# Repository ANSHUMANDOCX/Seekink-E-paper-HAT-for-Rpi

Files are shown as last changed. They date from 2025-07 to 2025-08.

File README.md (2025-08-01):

# Seekink-E-paper-HAT-for-Rpi
This a HAT for a epaper display for SEEKINK displays with raspberry pi Also can be used with any oher MCU using the 9 in connector. It supports multiple Displays of almost every Size

## Parts
- Raspberry Pi Zero 2 W
- 3.7 inch Epaper Display

## Plan
I needed a HAT that could be used with a Cheap Epaper dispaly paired with a raspberry pi. I found one on LCSC but it didnt have a HAT of that wa 100% compatible with it. 
So, i took reference from existing HATs and the Datasheet of the Epaper Display and made my own that could be attatched on top of raspberry pi WH.
I also added a 9 pin connector and a Voltage Level shifter so that i can connect it to most of the microcontrollers.

It can be programmed using the GxEPD2 Library
## PCB




## BOM
| S.No | Product Code | Description | Quantity | Total Price | Supplier | Category |LINK|
|---|---|---|---|---|---|---|---|
| 1 | C500051 | SK-3296S-01-L2 Slide Switch | 5 | $0.39 | LCSC | Passive Components  |https://lcsc.com/product-detail/Slide-Switches_XKB-Connection-SK-3296S-01-L2_C500051.html?s_z=n_C500051|
| 2 | C5224028 | PM2.54-1*9 Female Header (1x9P) | 5 | $0.52 | LCSC | Connectors |https://lcsc.com/product-detail/Female-Headers_ZHOURI-PM2-54-1-9_C5224028.html?s_z=n_C5224028%2509|
| 3 | C2977589 | 2.54-2*20 Female Header (2x20P) | 5 | $0.97 | LCSC | Connectors |https://lcsc.com/product-detail/Female-Headers_ZHOURI-2-54-2-20_C2977589.html?s_z=n_C2977589|
| 4 | C53406 | TXB0108PWR Level Shifter | 5 | $1.25 | LCSC | ICs |https://lcsc.com/product-detail/Translators-Level-Shifters_Texas-Instruments-TXB0108PWR_C53406.html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|
| 5 | C41416467 | SEEKINK E037A49 E-Ink Display | 1 | $7.22 | LCSC | Display |https://lcsc.com/product-detail/E-ink-Display_SEEKINK-E037A49_C41416467.html?s_z=n_C41416467|
| 6 | — | 0603 Resistors (47kΩ + 3Ω total)  | — | $0.25 | LCSC | Passive Components  |https://lcsc.com/product-detail/Chip-Resistor-Surface-Mount_FOJAN-FRC0603F3R00TS_C2930150.html  https://lcsc.com/product-detail/Chip-Resistor-Surface-Mount_YAGEO-RC0603FR-0747KL_C105579.html|
|||Shipping||3.75|LCSC|||
| | | **Total** | |14.52| | |
|||Raspberry Pi zero 2 W+ adapters | |20 |Silverline||https://www.silverlineelectronics.in/products/raspberry-pi-zero-2-silverline-india-authorised-distributor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 https://www.silverlineelectronics.in/products/usb-b-male-to-usb-a-female-otg-adaptor-official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  https://www.silverlineelectronics.in/products/official-raspberry-pi-micro-sd-card-adapter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|
|||PCB+ Shipping||12|JLCPCB|||
|||**TOTAL**||42|||

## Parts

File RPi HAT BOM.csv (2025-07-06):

S.No | Product Code | Description | Quantity | Total Price | Supplier
1 | C500051 | SK-3296S-01-L2 Slide Switch | 5 | 0.39 | LCSC
2 | C5224028 | PM2.54-1*9 Female Header (1x9P) | 5 | 0.52 | LCSC
3 | C2977589 | 2.54-2*20 Female Header (2x20P) | 5 | 0.97 | LCSC
4 | C53406 | TXB0108PWR Level Shifter | 5 | 1.25 | LCSC
5 | C41416467 | SEEKINK E037A49 E-Ink Display | 1 | 7.22 | LCSC
6 |  | 0603 Resistors (47k + 3R total) |  | 0.25 | LCSC
7 | https://www.silverlineelectronics.in/products/raspberry-pi-zero-2-silverline-india-authorised-distributor | Raspberry Pi Zero 2 W, Mini HDMI, OTG, SD card adapter |  | 21 | Silverline
8 |  | PCB |  | 4 | JLCPCB
9 |  | Shipping |  | 10
10 |  | Total |  | 45.6

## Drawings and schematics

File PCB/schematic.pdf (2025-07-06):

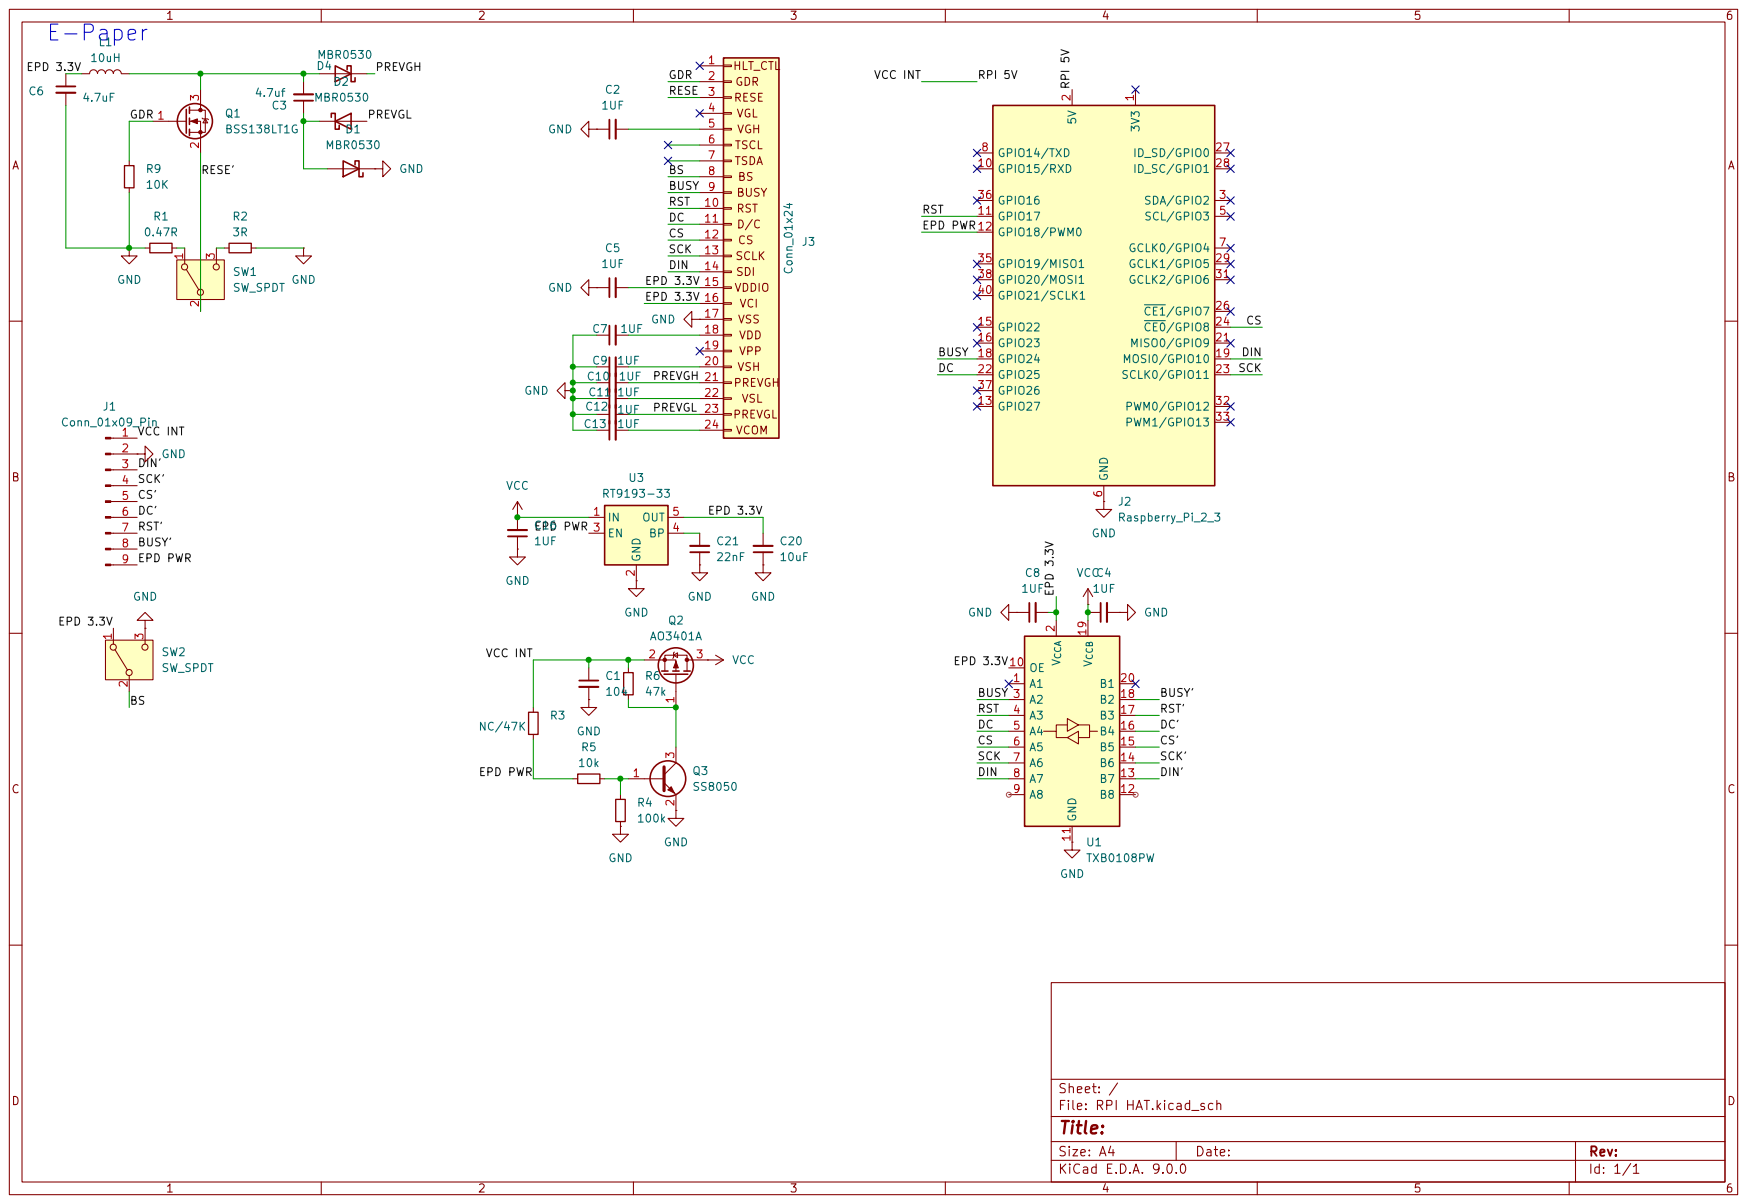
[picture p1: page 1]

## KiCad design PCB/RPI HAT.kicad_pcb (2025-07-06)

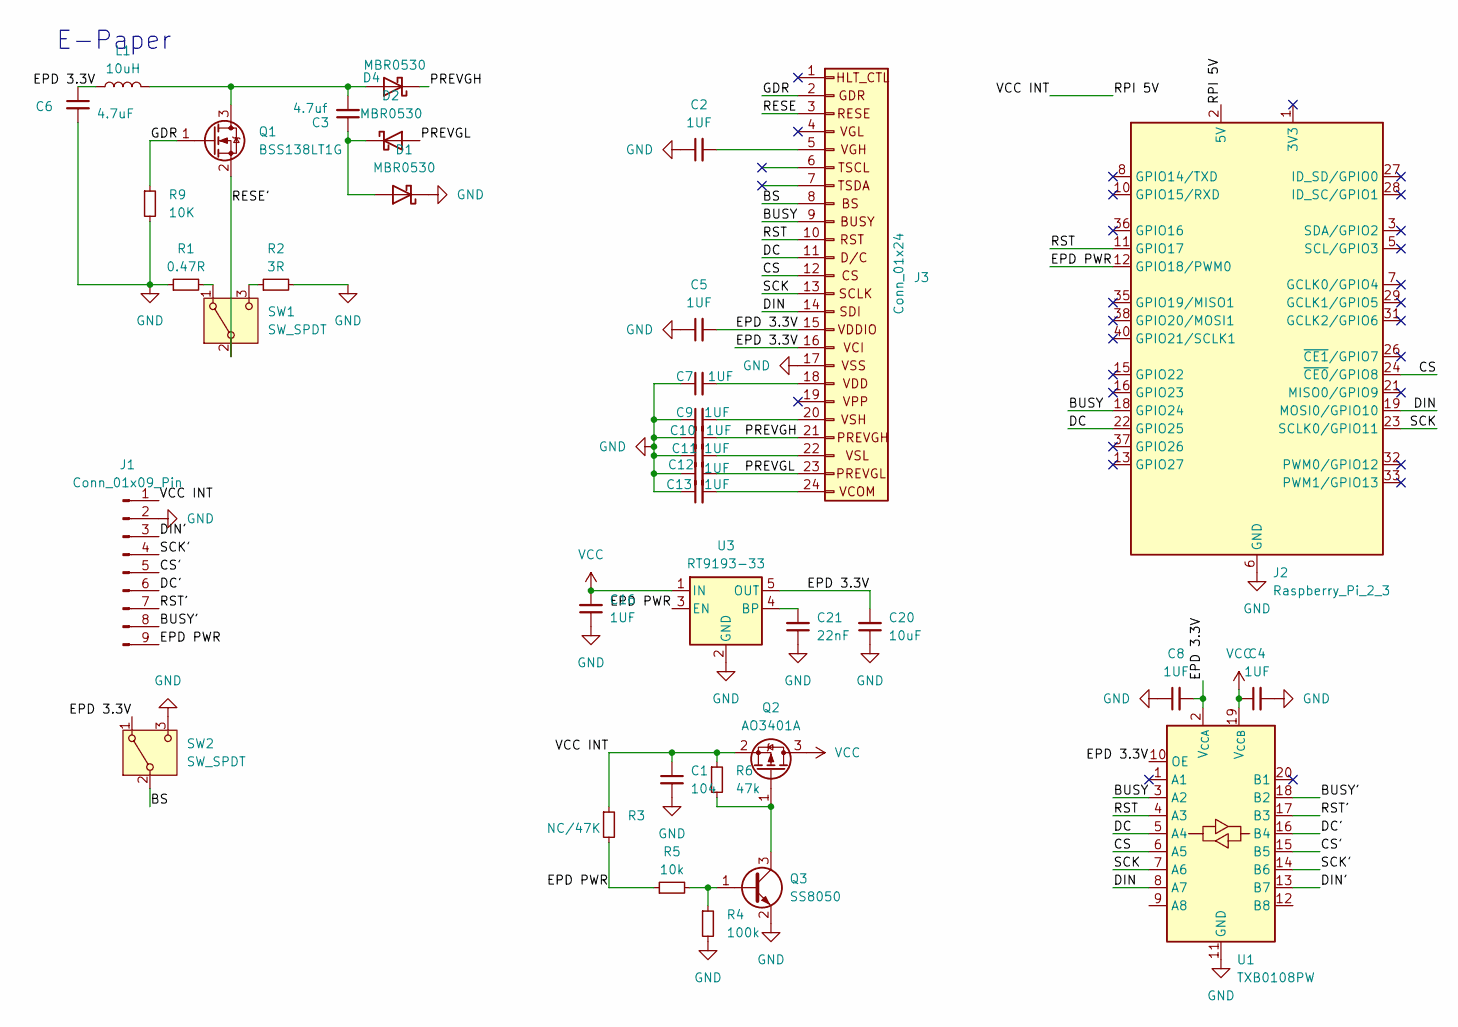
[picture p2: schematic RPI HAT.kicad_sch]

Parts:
C1: 104; C_0603_1608Metric
C2, C4, C5, C7, C8, C9, C10, C11, C12, C13, C16: 1UF; C_0603_1608Metric_Pad1.08x0.95mm_HandSolder
C3: 4.7uf; C_0603_1608Metric_Pad1.08x0.95mm_HandSolder
C6: 4.7uF; C_0603_1608Metric_Pad1.08x0.95mm_HandSolder
C20: 10uF; C_0603_1608Metric_Pad1.08x0.95mm_HandSolder
C21: 22nF; C_0603_1608Metric_Pad1.08x0.95mm_HandSolder
D1, D2, D4: MBR0530; D_SOD-123
J1: Conn_01x09_Pin; PinHeader_1x09_P2.54mm_Vertical
J2: Raspberry_Pi_2_3; PinHeader_2x20_P2.54mm_Vertical
J3: Conn_01x24; Hirose_FH12-24S-0.5SH_1x24-1MP_P0.50mm_Horizontal
L1: 10uH; L_Changjiang_FNR4020S
Q1: BSS138LT1G; SOT-23
Q2: AO3401A; SOT-23
Q3: SS8050; SOT-23
R1: 0.47R; R_0603_1608Metric_Pad0.98x0.95mm_HandSolder
R2: 3R; R_0603_1608Metric_Pad0.98x0.95mm_HandSolder
R3: NC/47K; R_0603_1608Metric_Pad0.98x0.95mm_HandSolder
R4: 100k; R_0603_1608Metric_Pad0.98x0.95mm_HandSolder
R5: 10k; R_0603_1608Metric_Pad0.98x0.95mm_HandSolder
R6: 47k; R_0603_1608Metric_Pad0.98x0.95mm_HandSolder
R9: 10K; R_0603_1608Metric_Pad0.98x0.95mm_HandSolder
SW1, SW2: SW_SPDT; SW-SMD_SK-3296S-01-L2
U1: TXB0108PW; TSSOP-20_4.4x6.5mm_P0.65mm
U3: RT9193-33; SOT-23-5

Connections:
/BS: J3.8, SW2.2 (B); also elsewhere on the board
/BUSY: J2.18 (GPIO24), J3.9, U1.3 (A2)
/BUSY': J1.8, U1.18 (B2)
/CS: J2.24 (~CE0/GPIO8), J3.12, U1.6 (A5)
/CS': J1.5, U1.15 (B5)
/DC: J2.22 (GPIO25), J3.11, U1.5 (A4)
/DC': J1.6, U1.16 (B4)
/DIN: J2.19 (MOSI0/GPIO10), J3.14, U1.8 (A7)
/DIN': J1.3, U1.13 (B7)
/EPD 3.3V: C5.2, C6.1, C8.2, C20.2, J3.15, J3.16, L1.1, SW2.1 (A), U1.2 (V_{CCA}), U1.10 (OE), U3.5 (OUT); also elsewhere on the board
/EPD PWR: J1.9, J2.12 (GPIO18/PWM0), R3.2, R5.1, U3.3 (EN)
/GDR: J3.2, Q1.1 (G), R9.1
/PREVGH: C10.2, D4.1 (K), J3.21
/PREVGL: C12.2, D2.2 (A), J3.23
/RESE: J3.3
/RESE': Q1.2 (S), SW1.2 (B)
/RPI 5V: C1.1, J1.1, J2.2 (5V), J2.4 (5V), Q2.2 (S), R3.1, R6.1
/RST: J2.11 (GPIO17), J3.10, U1.4 (A3)
/RST': J1.7, U1.17 (B3)
/SCK: J2.23 (SCLK0/GPIO11), J3.13, U1.7 (A6)
/SCK': J1.4, U1.14 (B6)
GND: C1.2, C2.1, C4.2, C5.1, C6.2, C7.1, C8.1, C9.1, C10.1, C11.1, C12.1, C13.1, C16.1, C20.1, C21.1, D1.1 (K), J1.2, J2.6 (GND), J2.9 (GND), J2.14 (GND), J2.20 (GND), J2.25 (GND), J2.30 (GND), J2.34 (GND), J2.39 (GND), J3.17, Q3.2 (E), R1.1, R2.2, R4.2, R9.2, SW2.3 (C), U1.11 (GND), U3.2 (GND); also elsewhere on the board
unnamed: C3.1, D1.2 (A), D2.1 (K)
unnamed: C3.2, D4.2 (A), L1.2, Q1.3 (D)
unnamed: C2.2, J3.5
unnamed: C7.2, J3.18
unnamed: C9.2, J3.20
unnamed: C11.2, J3.22
unnamed: C13.2, J3.24
unnamed: Q2.1 (G), Q3.3 (C), R6.2
unnamed: Q3.1 (B), R4.1, R5.2
unnamed: R1.2, SW1.1 (A)
unnamed: R2.1, SW1.3 (C)
unnamed: C21.2, U3.4 (BP)
VCC: C4.1, C16.2, Q2.3 (D), U1.19 (V_{CCB}), U3.1 (IN)

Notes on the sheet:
E-Paper

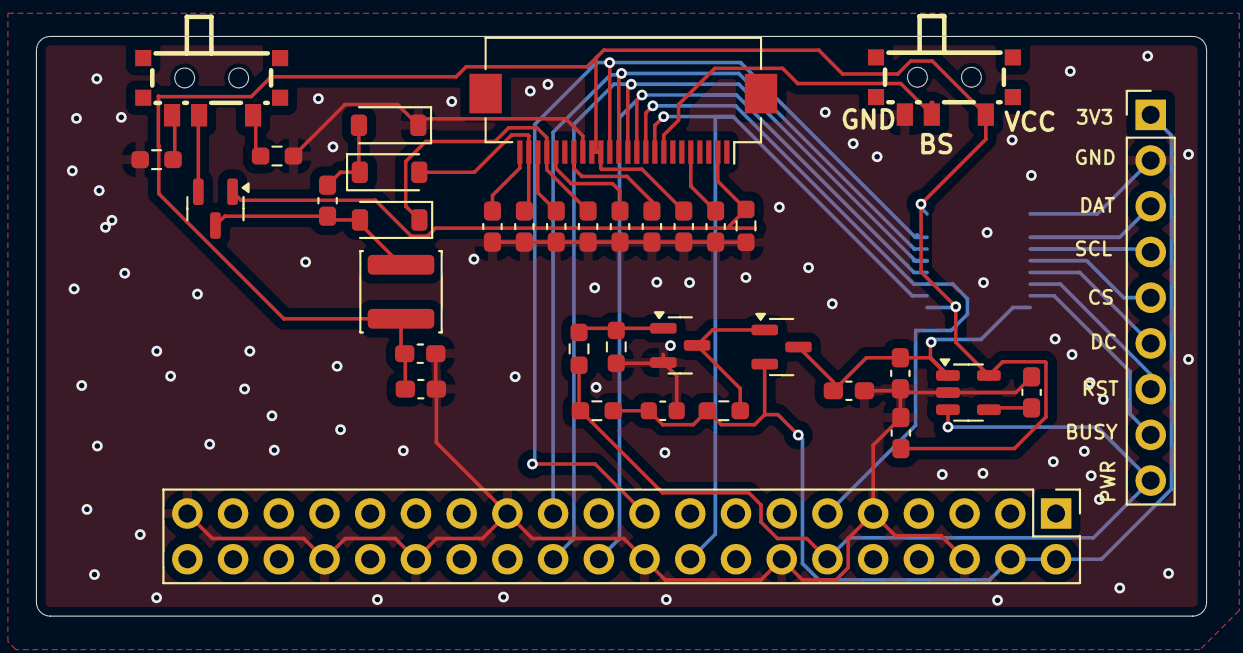
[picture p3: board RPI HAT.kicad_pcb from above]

Board: 2 copper layers, 65.0 x 32.2 mm, 37 parts (1 on the bottom side), 34 nets.

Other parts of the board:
BS: SW_SPDT; SW-SMD_SK-3296S-01-L2

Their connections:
/BS: BS.2 (B); also elsewhere on the board
/EPD 3.3V: BS.1 (A); also elsewhere on the board
GND: BS.3 (C); also elsewhere on the board

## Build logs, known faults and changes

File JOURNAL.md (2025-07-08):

---
title: "Epapar HAT"
author: "Anshuman Tripathy"
description: "It is a Epaper to be used with a SEEKINK display and Raspberry Pi "
created_at: "2025-07-03"
total_time_spent: "11 Hrs"
---

## **DAY 1- 3 July 2025- Starting OUT**

there are no epaper hat that exist for the epaper displays made by seekink. These are cheap but there are no peripherals to use with it. so i want to make one to use with a raspberry pi

started out by reading datasheets for the seekink display and figuring out the circuit and the component

time spent- 2hr

## **DAY 2 - 4 July 2025- Basic Circuit**

Completed the necessary control citcuit for EPD and voltage shifting 



 Time spent - 2 HR

## **DAY 3 - 6 July 2025 - Interfaced RPi and Complete PCB**

Completed the power control logic and the RPi header connections. Also added a additional 9 pin connector to connect with other MCUs
Assigned the components ,started and complted the PCB. Took some time searching about the Pinouts for RPI



time spent - 7 hr
